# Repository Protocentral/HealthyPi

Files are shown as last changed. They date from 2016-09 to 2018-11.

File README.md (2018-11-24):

# This repository is OBSOLETE. Please visit https://github.com/Protocentral/protocentral-healthypi-v3 for the current version. 

# ProtoCentral HealthyPi HAT for Raspberry Pi

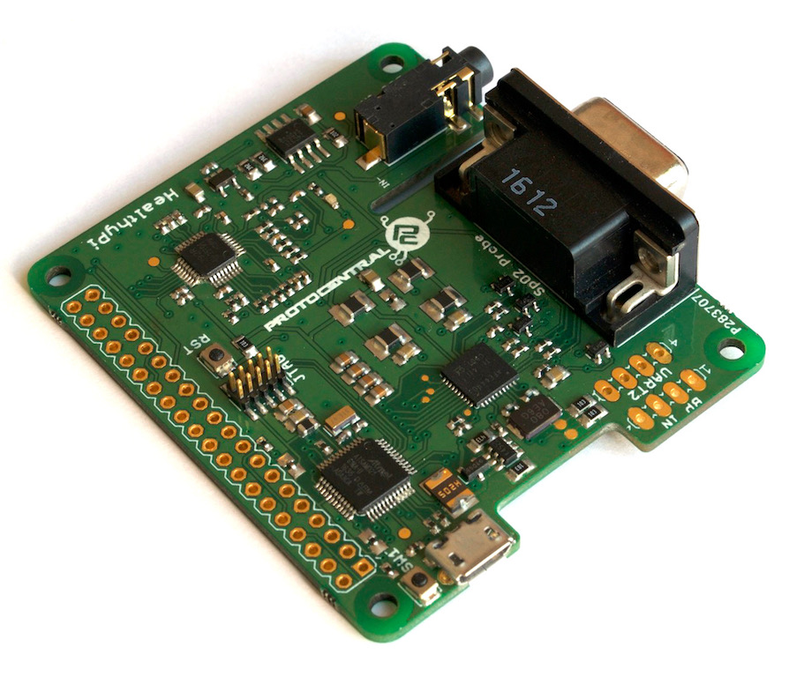
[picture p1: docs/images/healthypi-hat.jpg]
Healthy Pi Hat


This HAT for Raspberry Pi 3 / 2 includes vital patient monitoring including ECG, respiration, pulse oximetry and features options to add blood pressure and body temperature sensing.

This is a one-of-a-kind, all-in-one HAT for your Raspberry Pi 2 /3 computer. Just plug it into the Raspberry Pi, install the graphical visualisation software and start using. Unlike available shields and breakouts that we carry for Arduino, this board combines all the functions into a a single board.

Repository Contents
-------------------
* **/firmware** - Atmel studio  and aduino example sketches.
* **/Hardware** - All Eagle design files (.brd, .sch)
* **/extras** - includes the datasheet
* **/gui** - HealthyPi GUI for Raspberry Pi and PC
* **/docs** - Additional Documentation

Getting Started (On Raspberry Pi):
----------------------------------

Mount ProtoCentral's Healthy PI Hat carefully onto the Raspberry Pi Board's GPIO Pins. And connect this setup with the Raspberry Pi's Display or HDMI Monitor. The Hat communicate with Raspberry Pi using UART interface. Connect the ECG electrodes and SPO2 Probe to the ProtoCentral's Healthy PI Hat.

It's now easy to get started with our brand-new installation script. Just follow the following steps on your Raspberry Pi.

To start, open up the terminal window (Menu -> Accessories -> Terminal) on Raspbian running on your Raspberry Pi:

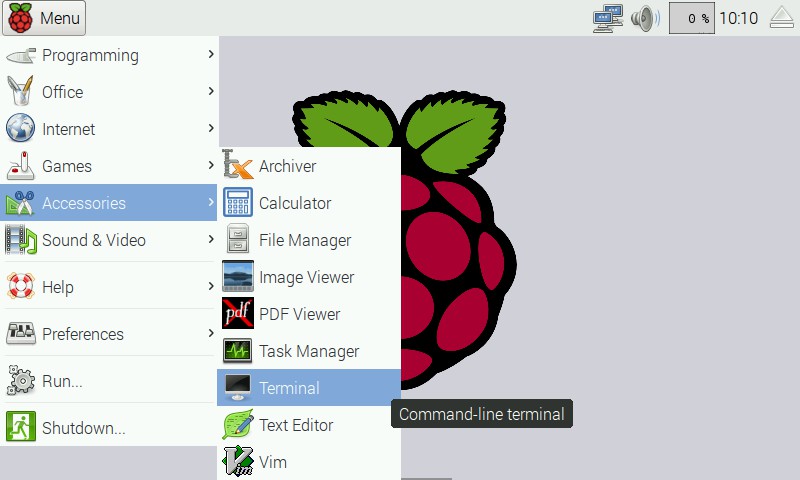
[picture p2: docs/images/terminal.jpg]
Open the terminal


In the terminal window, type the following lines. 

```bash
curl -sS http://pi.protocentral.com/pi.sh | sudo bash
```

It really is as simple as that !!

This code will install all the required overlays, configuration and application files to get the Healthy Pi up and running.

After the script reboots, you should be able to see the GUI display on the screen

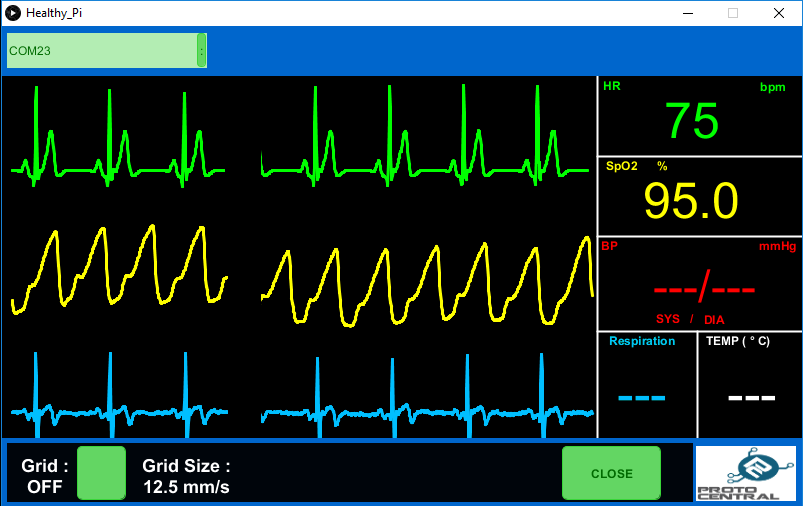
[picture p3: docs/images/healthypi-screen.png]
GUI in Processing


###This completes the install!

If the above script does not work for you and would like to do a manual installation or would like to customize the code, check out [Advanced HealthyPi] (/docs/advanced-healthypi.md).

Using the HealthyPi GUI on Windows, MacOS and Linux
---------------------------------------------------
The HealthyPi board now streams the same data on the on-board USB port. This allows you to get the same data that goes to the Raspberry Pi, now on your desktop PC as well. 

Java 8 is required on all platforms for running the processing-based GUI application. You can download Java for your platform from the following link.

[https://java.com/en/download/](https://java.com/en/download/)

#### Installing drivers (only for Windows)

HealthyPi uses the same drivers as an Arduino Zero. Once plugged in to the USB port, the device would be recognized as an "Unknown Device". You can locate the device is the Windows Device Manager and manually install the drivers provided in the "drivers" folder in the Windows Executable ZIP archive provided.

MacOS and Linux do not need any drivers to be installed.

### Processing GUI Installation

Download the zip file containing the executable files from the following links for 32-bit/64-bit Windows. If you do not know if you have a 64-bit or 32-bit computer, please download the 32-bit version.

* [Windows 32-bit Executable (ZIP)](https://github.com/Protocentral/HealthyPi/releases/download/v0.2/healthypi_gui_win32.zip)
* [Windows 64-bit Executable (ZIP)](https://github.com/Protocentral/HealthyPi/releases/download/v0.2/healthypi_gui_win64.zip)
* [MacOS Executable (ZIP)](https://github.com/Protocentral/HealthyPi/releases/download/v0.2/healthypi_gui_macos.zip)
* [Linux 32-bit Executable (ZIP)](https://github.com/Protocentral/HealthyPi/releases/download/v0.2/healthypi_gui_linux32.zip)
* [Linux 64-bit Executable (ZIP)](https://github.com/Protocentral/HealthyPi/releases/download/v0.2/healthypi_gui_linux64.zip)

Simply download the appropriate file for your operating system, unzip the contents and run the executable program contained in it. 

Programming the on-board SAMD21 microcontroller
--------------------------------------------------

HealthyPi now supports programming using Arduino ! 

If you wish to program your own code on the HealthyPi board, check out [Modifying and recompiling HealthyPi Firmware](/docs/recompiling-firmware.md).

Connecting the ECG Electrodes
------------------------------
 A 3-electrode cable along with a standard stereo jack is provided along with the shield to connect the electrodes to the  board. 
 The other side of the electrode connector would connect to snap-on electrodes attached to the body. For testing purposes,    you can use an ECG simulator to provide inputs to the board. 

 Warning:
 When connecting the electodes to the body, it is safer to disconnect the mains power source to the Arduino. For example, if  you are using the Arduino along with a laptop, disconnecting the battery charger from the laptop would be a safe option.
 
Placing the Electrodes on the body
---------------------------------
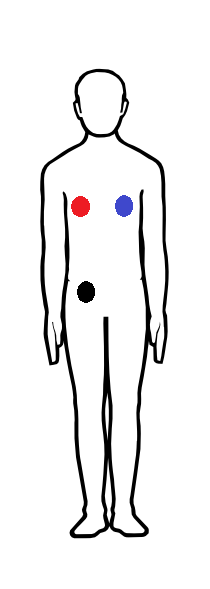
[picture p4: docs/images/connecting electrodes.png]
Wearing the Electrode


License Information
===================

This product is open source! Both, our hardware and software are open source and licensed under the following licenses:

Hardware
---------

**All hardware is released under [Creative Commons Share-alike 4.0 International](http://creativecommons.org/licenses/by-sa/4.0/).**



Software
--------

**All software is released under the MIT License(http://opensource.org/licenses/MIT).**

Please check [*LICENSE.md*](LICENSE.md) for detailed license descriptions.

THE SOFTWARE IS PROVIDED "AS IS", WITHOUT WARRANTY OF ANY KIND, EXPRESS OR
IMPLIED, INCLUDING BUT NOT LIMITED TO THE WARRANTIES OF MERCHANTABILITY,
FITNESS FOR A PARTICULAR PURPOSE AND NONINFRINGEMENT. IN NO EVENT SHALL THE
AUTHORS OR COPYRIGHT HOLDERS BE LIABLE FOR ANY CLAIM, DAMAGES OR OTHER
LIABILITY, WHETHER IN AN ACTION OF CONTRACT, TORT OR OTHERWISE, ARISING FROM,
OUT OF OR IN CONNECTION WITH THE SOFTWARE OR THE USE OR OTHER DEALINGS IN THE
SOFTWARE.

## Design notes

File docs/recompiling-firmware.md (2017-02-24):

Recompiling Firmware:
---------------------

All boards shipped on or after February 20, 2017 come **pre-installed** with the Arduino Zero/M0 bootloader and the Arduino-based code. This means that you no longer need a JTAG programmer or Atmel Studio to customize the code on the SAMD21 microcontroller on the board. 

In addition, the new Arduino-based firmware now **streams over USB** the same data sent to the Raspberry Pi's UART pins. This now means that the HealthyPi works not just with a Raspberry Pi, but any Windows/MAC/Linux machine that supports Java and Processing.
 
However, if you would like to edit the firmware, here's the steps to do that in Atmel Studio 7:

* **Atmel Studio 7** :
Please note that Atmel Studio 7 is available only for Windows and does not support Mac and Linux . This is the IDE software that can do step & memory debugging and its only for Windows. Also you have to make an account on Atmel's site. The IDE can be downloaded from [Atmel Studio's Official Website](http://www.atmel.com/tools/atmelstudio.aspx)

**Load the Healthy Pi Source Code**

* **Step 1 :** Start by launching Atmel Studio 7.

* **Step 2 :** Open the Project file in the firmware folder of this git respitory

* **Step 3 :** You'll see the following, where the sketch is in a window, you can edit the code here if you like.

**Debugger**

You need a debugger to load the code into the SAMD21G18A. Atmel-ICE will help get from here http://www.atmel.com/tools/atatmel-ice.aspx

**Step 1 : Set Up and Check Interface**
* Attach the chip & debugger

**Step 2 : Identify Interface**
* OK now you have your debugger plugged in, its good to check that it works, select Device Programming.
* Choose "Device Programmer" from "Tools" Menu
* Programming window will be open.
* Select the programmer from the drop down box. Select interface as “SWD”. Click on “Apply”.
* Now read the Power and Device ID. If you are able to read the Device ID then the interface is fine.

**Step 3 : Build & Start Debugging**
* Ok close out the modal programming window and build the program. If there are no error, then your build will be successful.

**Step 4 : Run & Upload**
* You will see a window appearing to select a debugging tool. Select the tool and interface.
* Once done, go back and Re-run Program without debugging.

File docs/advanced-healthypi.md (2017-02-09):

Advanced HealthyPi
==================
This section is for those who want to do a manual installation of HealthyPi, those who want to modify with the code and generally play with the hardware.

For the simple way to setup HealthyPi on Raspberry Pi, check out the [getting started guide](https://github.com/protocentral/healthypi).

You can buy [HealthyPi at ProtoCentral](https://www.protocentral.com/healthypi)

Setting up Raspberry Pi for UART Communication
----------------------------------------------
The following are the steps involved to get Raspberry Pi ready for a patient monitor.

###Step 1 : Install and Update the OS

* Install the Raspbian OS in Raspberry Pi. The image file can be downloaded from the [Raspberry Pi's official website](https://www.raspberrypi.org/downloads/).

* Once the installation finishes, update the system with the following command in the Terminal:
		
		sudo apt-get update
		sudo apt-get upgrade

###Step 2 : Enable the UART0 device tree overlay

As the ProtoCentral's Healthy Pi Hat communicates with the Raspberry Pi board via GPIO 14/15 which on the Model B, B+ and Pi2 is mapped to UART0. However on the Pi3 these pins are mapped to UART1 since UART0 is now used for the bluetooth module. As UART1 is not stable because it is dependent to clock speed which can change with the CPU load, we have to disable the Bluetooth module and map UART1 back to UART0 (tty/AMA0).

* Run the following command

		sudo nano /boot/config.txt

* Add this line to the end of the file

		dtoverlay=pi3-miniuart-bt

###Step 3 : Disable Serial command line console

* To disable the Serial Console edit the file using

		sudo nano /boot/cmdline.txt 

* Remove the word phase "console=serial0,115200" or "console=ttyAMA0,115200".

* Save the file and close

###Step 4 : Reboot your Raspberry Pi

* Now your Pi is ready to integrate with ProtoCentral's Healthy Pi Hat.

HealthyPi GUI based on Processing
---------------------------------

[Processing](https://processing.org/) has been used to develop the visualization software for the HealthyPi. 

Processing is an open source framework based on Java. The following are the steps to get the visualization software ready for patient monitor:

###Step 1 : Download Processing IDE for your HOST COMPUTER operating system

a. Latest Version of the Processing IDE can be downloaded from the following link:

[Download Processing](https://processing.org/download/?processing)

b. Unzip and install the file once downloaded.

###Step 2 : Download the Processing code for the HealthyPi GUI

a. Download the necessary files & directories or clone to your desktop from GitHub.

b. Unzipping the archive should make a folder by name HealthyPi that contains the visualisation code.

c. Locate the Processing sketchbook directory on your computer. This should have been created automatically when you installed processing. Depending on your operating system, the path will be as follows:

* On Windows : C:/My Documents/Processing
* On MAC : /Users/your_user_name/Documents/Processing
* On Linux : /Home/your_user_name/sketchbook/

**Note:** This directory appears as "Processing" on Windows/Mac, and goes by the name "Sketchbook" on Linux. Create a subdirectory by name "libraries if one doesn't exist already.

d. From the above mentioned "HealthyPi" directory Copy/Move the contents of the HealthyPi/Processing/HealthyPi folder to the Processing sketchbook directory which is also mentioned above (Locate the Processing sketchbook)

e. Finally, copy the "controlP5 & G4P" folders from HealthyPi/Processing/libraries/ and paste them into the libraries directory of your Processing sketchbook.

###Step 3 : Upload the Processing code Raspberry Pi

* In Processing IDE, Select "Tools" from the menu and choose, "Add tools".

* Select "Upload To Pi" tool and click Install button which is present in the button right corner as shown in the below image.

![Upload To Pi in Processing]
(https://github.com/Protocentral/HealthyPi/blob/master/extras/Images/Upload_To_Pi.png)

* Now, connect your raspberry pi to the internet with the same network as your laptop is connected.

* Select "Tools" menu and choose "Upload to Pi" option from the list.

* If any error occured in uploading the code, check for the internet connection and repeat the process.

Firmware:
---------

The board is pre-loaded with the firmware which works stand alone with the Rpi without any firmware development or loading required. 

However, if you want to edit the firmware, you can follow the steps in this [document] (/docs/recompiling-firmware.md)

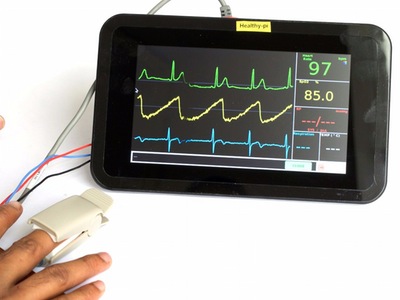
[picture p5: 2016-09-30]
docs/images/healthypi-run.jpg

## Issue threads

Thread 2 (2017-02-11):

Documentation for the serial protocol

abhas, 2017-02-11:
I see that the HealthyPi communicates with the Raspberry Pi using a serial protocol. But the only way to understand how this happens would be to study the Processing source code. If you could share any documentation of the serial protocol, that would be very helpful in using the board to gather and store metrics using time-series databases, for example. Or just write some simple C or Python code to understand how the board works.

protocentralashwin, 2017-02-12:
We will document the protocol as well, but for now you can check the trasnmit protocol format in the following code:

https://github.com/Protocentral/HealthyPi/blob/master/firmware/src/main.c

Closed 2017-02-12.

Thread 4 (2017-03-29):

Wrong Baudrate in INO?

SvenHi, 2017-03-29:
In the arduino sktech, there is the baud rate config for 115200
in all GUI and Atmel Studio project 57600.

=> Is the Arduino sketch really up to date?
Even if I change the baud rate, I get no matching values in the GUI

VenkateshBhat, 2017-03-30:
Hello SvenHi,
The SerialUSB on Arduino Zero is a  is an emulated serial port (USB-CDC). The SerialUSB class is a special Serial instance which use the hardware USB the speed will always be 115200.

SvenHi, 2017-03-30:
 

Thank you for response!

Does this mean, I have to change the Baudrate in the Processing GUI (for USB)?

Original code healthypi_desktop.pde:     port = new Serial(this, selectedPort, 57600);

Or does this setting not matter?

In case this setting does not cause conflict with the 115200 baudrate of CDC, I have to search for other issues on my setup.

I have the problem, that the device does work in general with Atmel Studio firmware on Raspberry.

If I replace the flash with Arduino Zero bootloader, download INO via Arduino, and use the PC GUI (Win10,64Bit)

then I have in general communication between device and GUI, but no valid data in visualization...

Best regard

Gesendet: Donnerstag, 30. März 2017 um 07:33 Uhr
Von: VenkateshBhat <notifications@github.com>
An: Protocentral/HealthyPi <HealthyPi@noreply.github.com>
Cc: SvenHi <s.hirsch@gmx.net>, Author <author@noreply.github.com>
Betreff: Re: [Protocentral/HealthyPi] Wrong Baudrate in INO? (#4)

Hello SvenHi,
The SerialUSB on Arduino Zero is a is an emulated serial port (USB-CDC). The SerialUSB class is a special Serial instance which use the hardware USB the speed will always be 115200.

—
You are receiving this because you authored the thread.
Reply to this email directly, view it on GitHub, or mute the thread.

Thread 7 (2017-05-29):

ECG Not working

saisrinivas25, 2017-05-29:
I tried to connect the electrodes as mentioned in the diagram.
But it doesn't work properly and I am getting an unusual heart rate on the monitor.
It keeps on fluctuating. Kindly let me know the proper connections in detail.

VenkateshBhat, 2017-05-29:
Could you please attach the screenshot of signals obtained?

saisrinivas25, 2017-05-29:
Here are the screenshots.
Somehow, the record was not working on my PC.
So I have taken these snapshots.
Issue is only with ECG, SpO2 is working fine I guess.
And I have red, blue and black coloured electrodes. please let me know the electrodes' spec properly.
I mean, which is RA, LA & LL?
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

VenkateshBhat, 2017-05-29:
Thanks for sharing, where did you place the electrodes? was it on the chest?. Baseline is wandering too much.
RA : Red
LA: Green
LL : Black

saisrinivas25, 2017-05-29:
Thanks for the info. So, I had placed the electrodes in proper positions.
I had tried placing the electrodes both on the chest and on limbs as well.
But I got the same kind of fluctuating reading.

saisrinivas25, 2017-05-29:
What is the baseline you are referring to?
I understand that green is heart rate, blue is respiration and yellow is SpO2.
But, is there anything else I need to understand from the GUI?
And why there are readings on the GUI even when there are no devices(ECG or SpO2) connected to the HealthyPI?
Please help

VenkateshBhat, 2017-05-29:
I am referring to the ECG signal moving up and down  rather than straight.  Are you using the latest Ui?

saisrinivas25, 2017-05-29:
Yes. I am using V0.3

saisrinivas25, 2017-05-30:
Can you please tell me what the conclusion is?
Is the HealthyPi hat faulty? It is showing readings when there is no device connected also.
Or how can I get proper readings of my vitals?
Please advise

famesjranko, 2022-04-07:
I just got the latest v4 and also has readings showing when no device connected.   I think there are serious design/implementation issues with this device...

MohammedHM, 2022-04-08:
Hi Andrew,

Can you please share the screenshots of the output, and the image of your HealthyPi setup.

famesjranko, 2022-04-20:
Hey MohammedHM,

Thanks for responding.   I've been trying to figure out the packet data structure and encoding come through the raspberry pi port serial /dev/ttyAMA0 without any luck.   Could you please point me towards the documentation for this?

Looking at the gui.java file located in the source directory, I was able to see that you are writing to CSV file and thought about editing that section to parse the data where I want to send it, but I found that I can't compile that file and the actual code being used is in .jar files and thus inaccessible to me.   Would it be possible to have access to these files for easier modding?

The reason I was interested in your project and bought the device was the open-source nature of it, but I've found the software to be opaque rather than transparent...

I will provide screenshots shortly, but simply put I get a heart rate even when there are no sensors connected, and the spO2 sensor only gives values when the ecg sensors are connected - not sure if that last one is a design or a bug...

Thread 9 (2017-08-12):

No Raspberry Pi serial data from Arduino firmware

GothAck, 2017-08-12:
The firmware outputs via SerialUSB but I cannot see any code to output to the pi via GPIO.

abhas, 2017-08-12:
I think the HealthyPi board talks to the RPi via the serial port on the GPIO pins. So it doesn't use the GPIO *per se* -- only the serial port on the GPIO.

GothAck, 2017-08-12:
It is meant to, yes, but after flashing the latest arduino code I see no data being sent to the RPi. I've tried searching through the code but can only see transmission of the packets via SerialUSB, which IIRC is just the USB CDC serial port. The USB serial device is transmitting data just fine, just not via the RPi GPIO header.

protocentralashwin, 2017-08-12:
thanks guys @GothAck and @abhas . We have moved the latest version of this repo for HealthyPi v3 to https://github.com/Protocentral/protocentral-healthypi-v3/

The code is actually sending to both _SerialUSB_ as well as _Serial_

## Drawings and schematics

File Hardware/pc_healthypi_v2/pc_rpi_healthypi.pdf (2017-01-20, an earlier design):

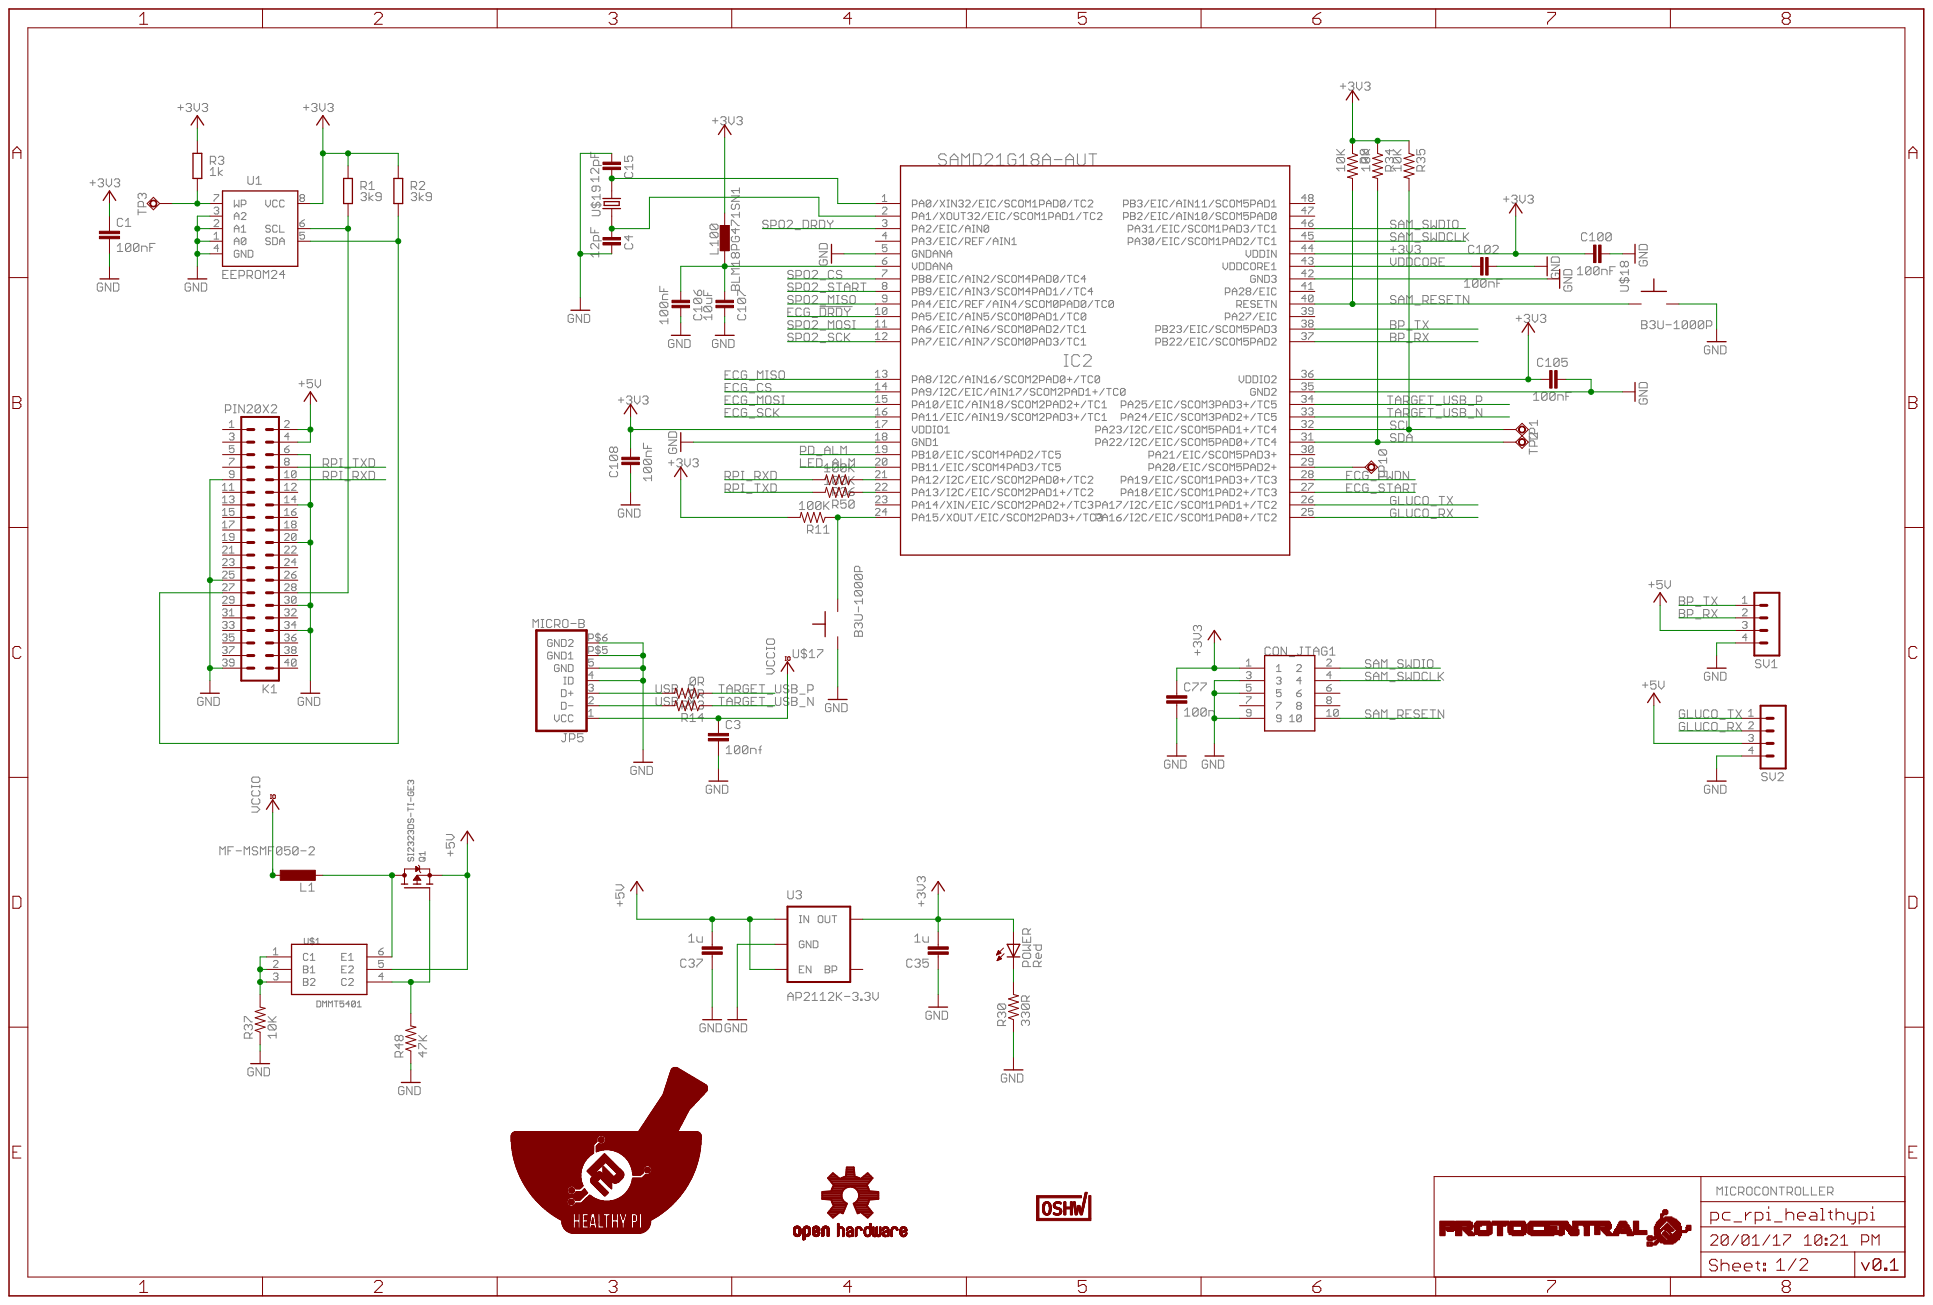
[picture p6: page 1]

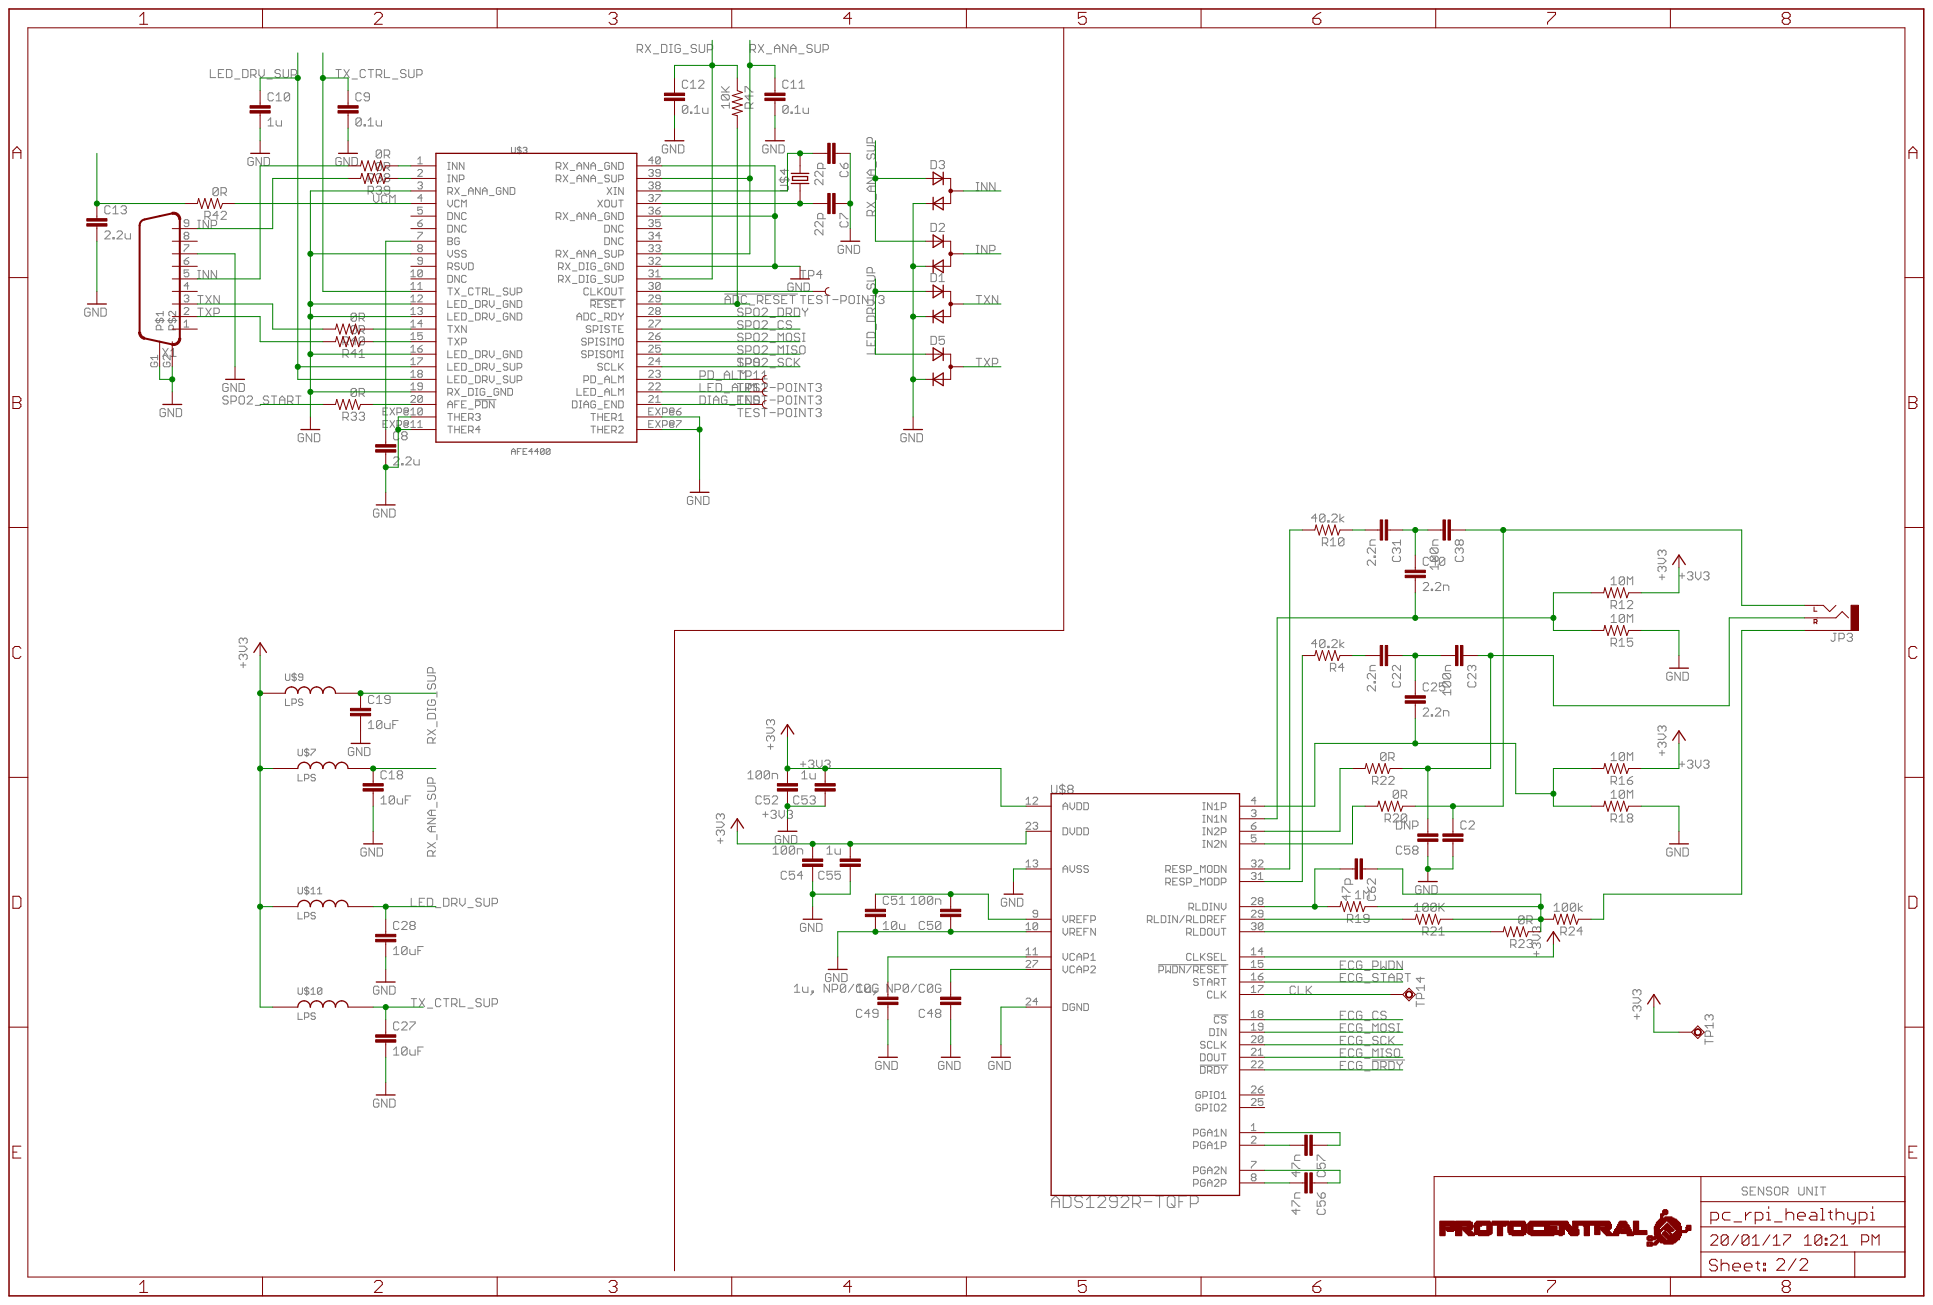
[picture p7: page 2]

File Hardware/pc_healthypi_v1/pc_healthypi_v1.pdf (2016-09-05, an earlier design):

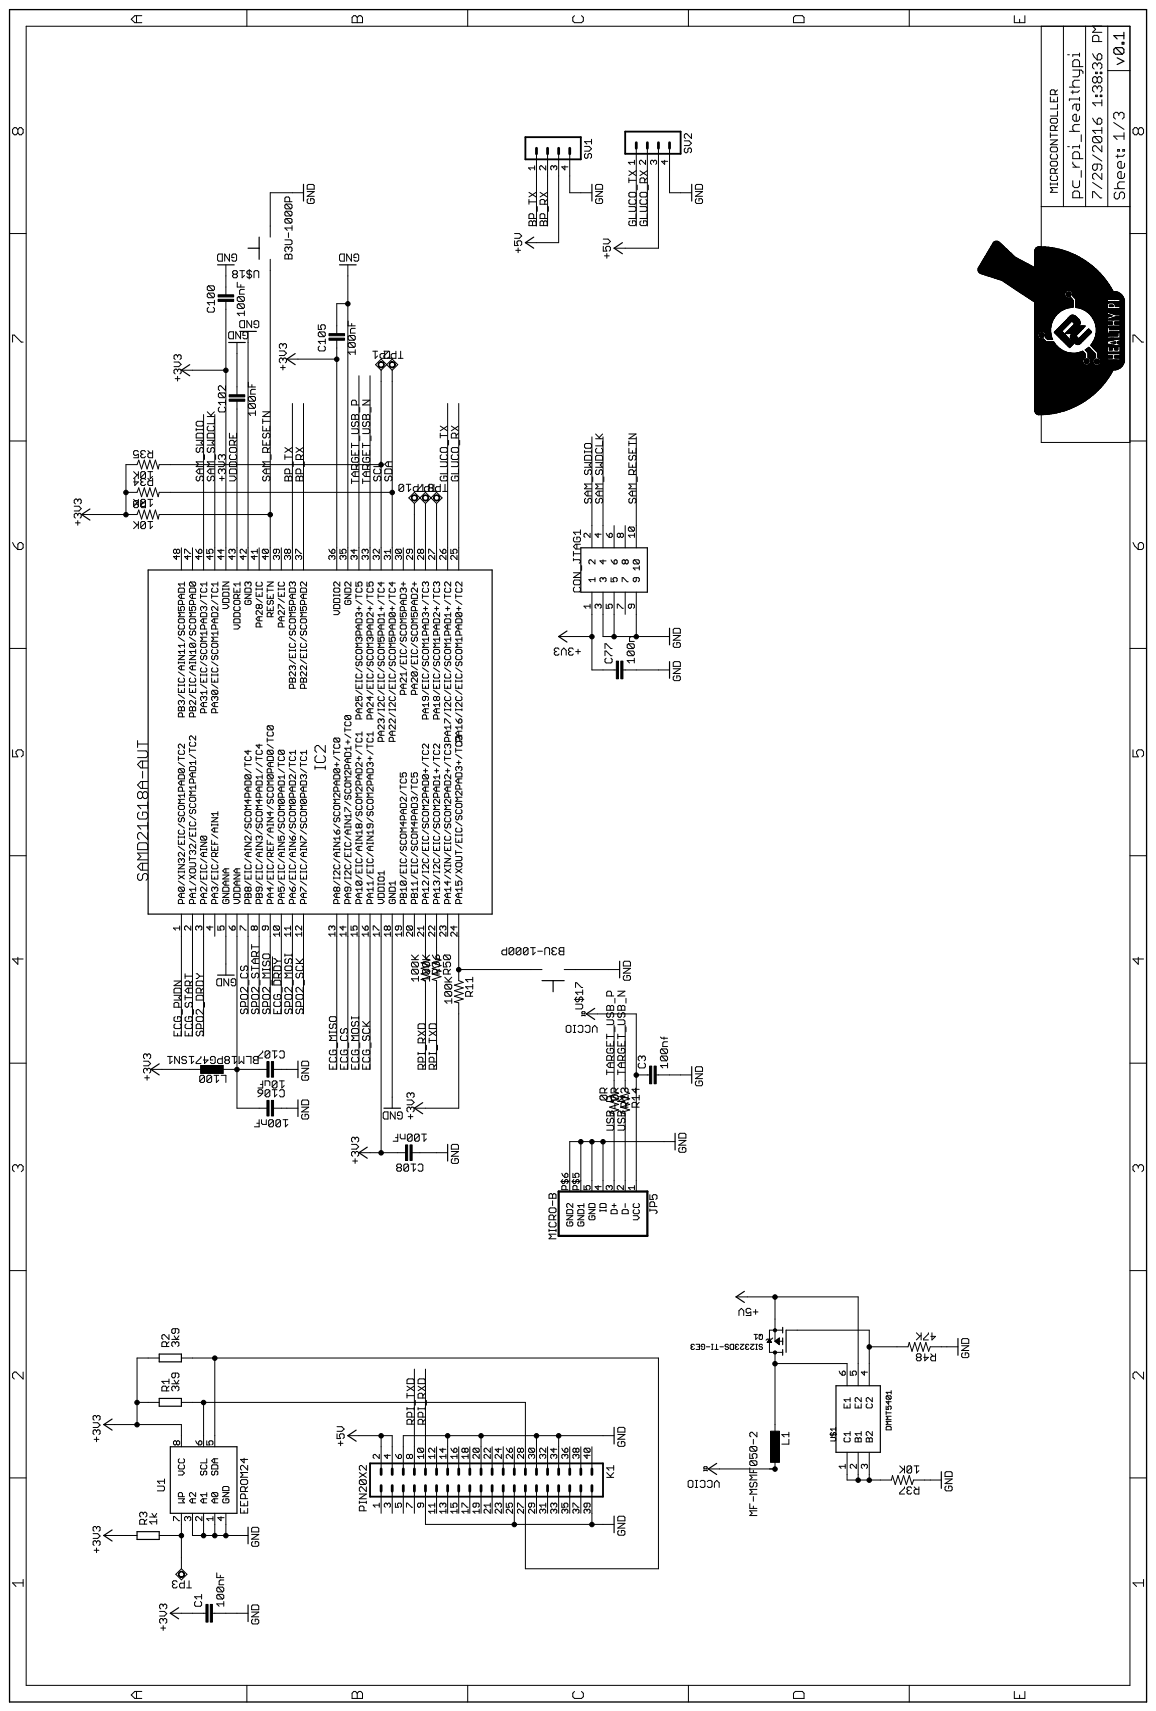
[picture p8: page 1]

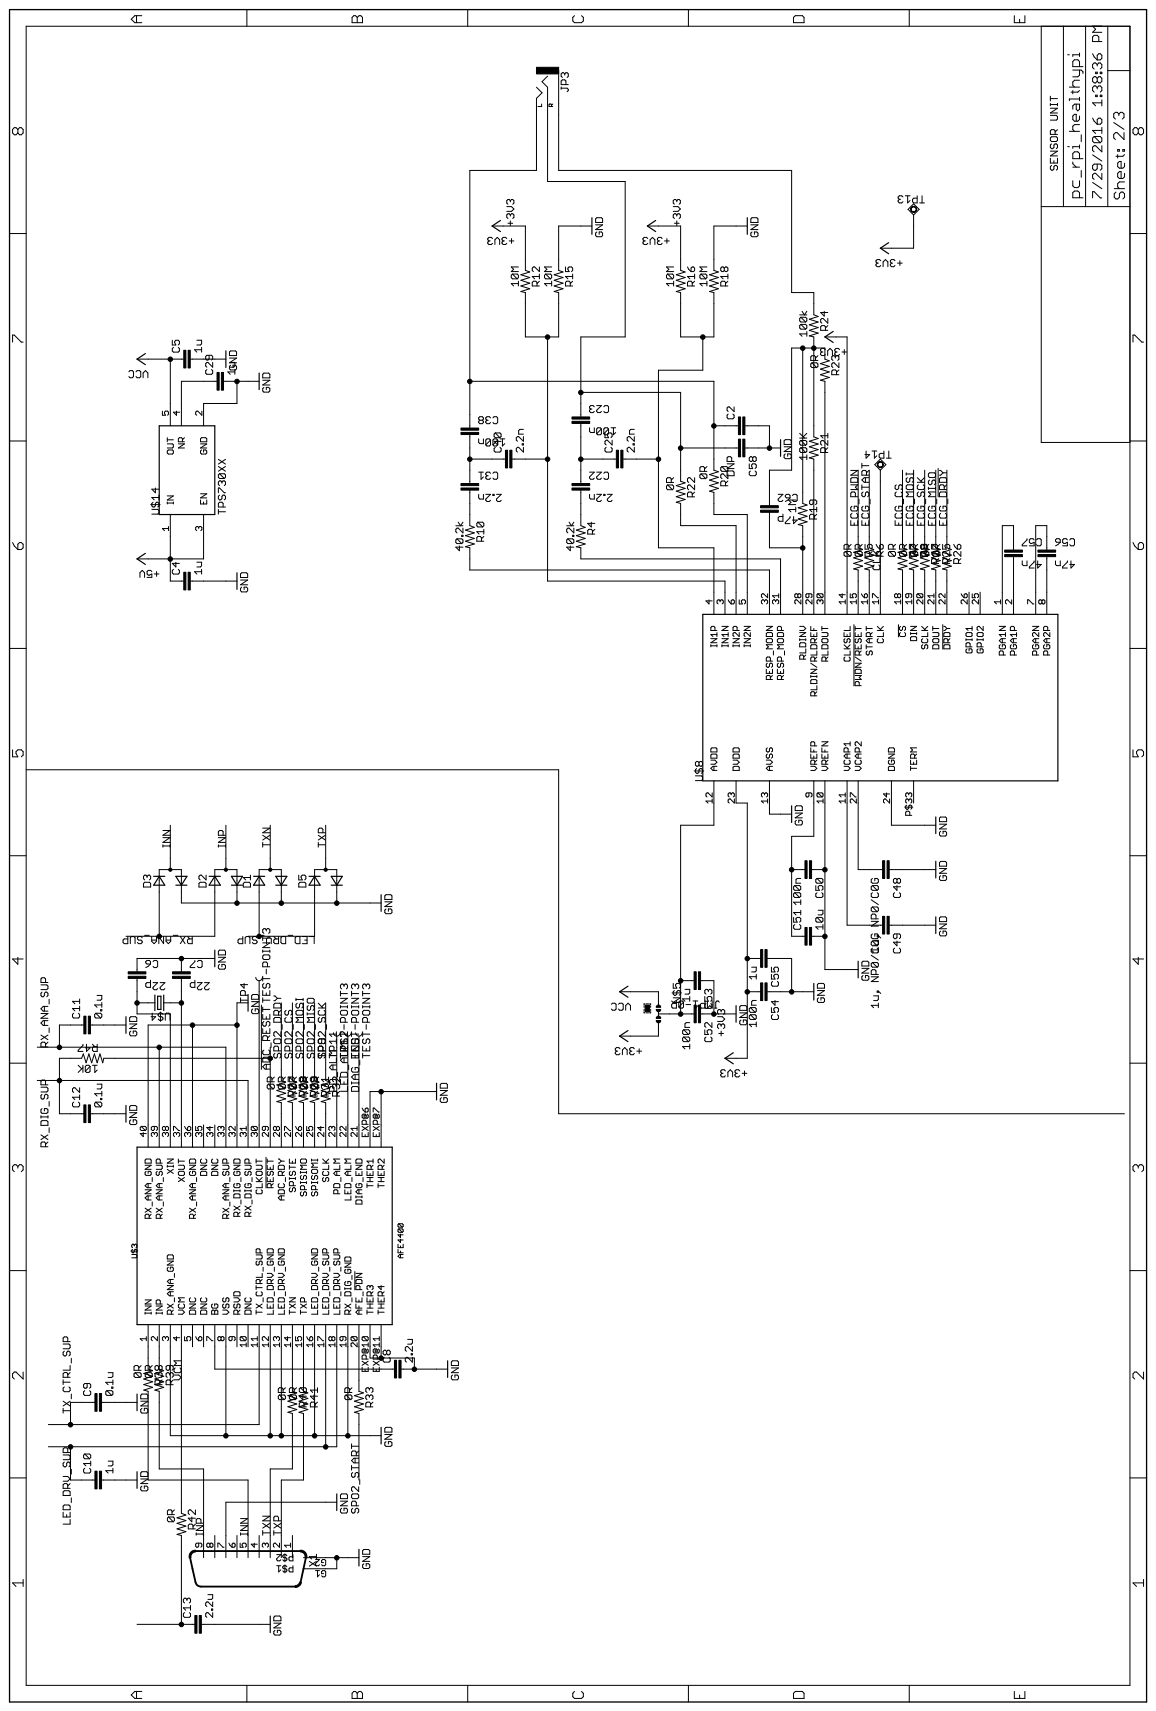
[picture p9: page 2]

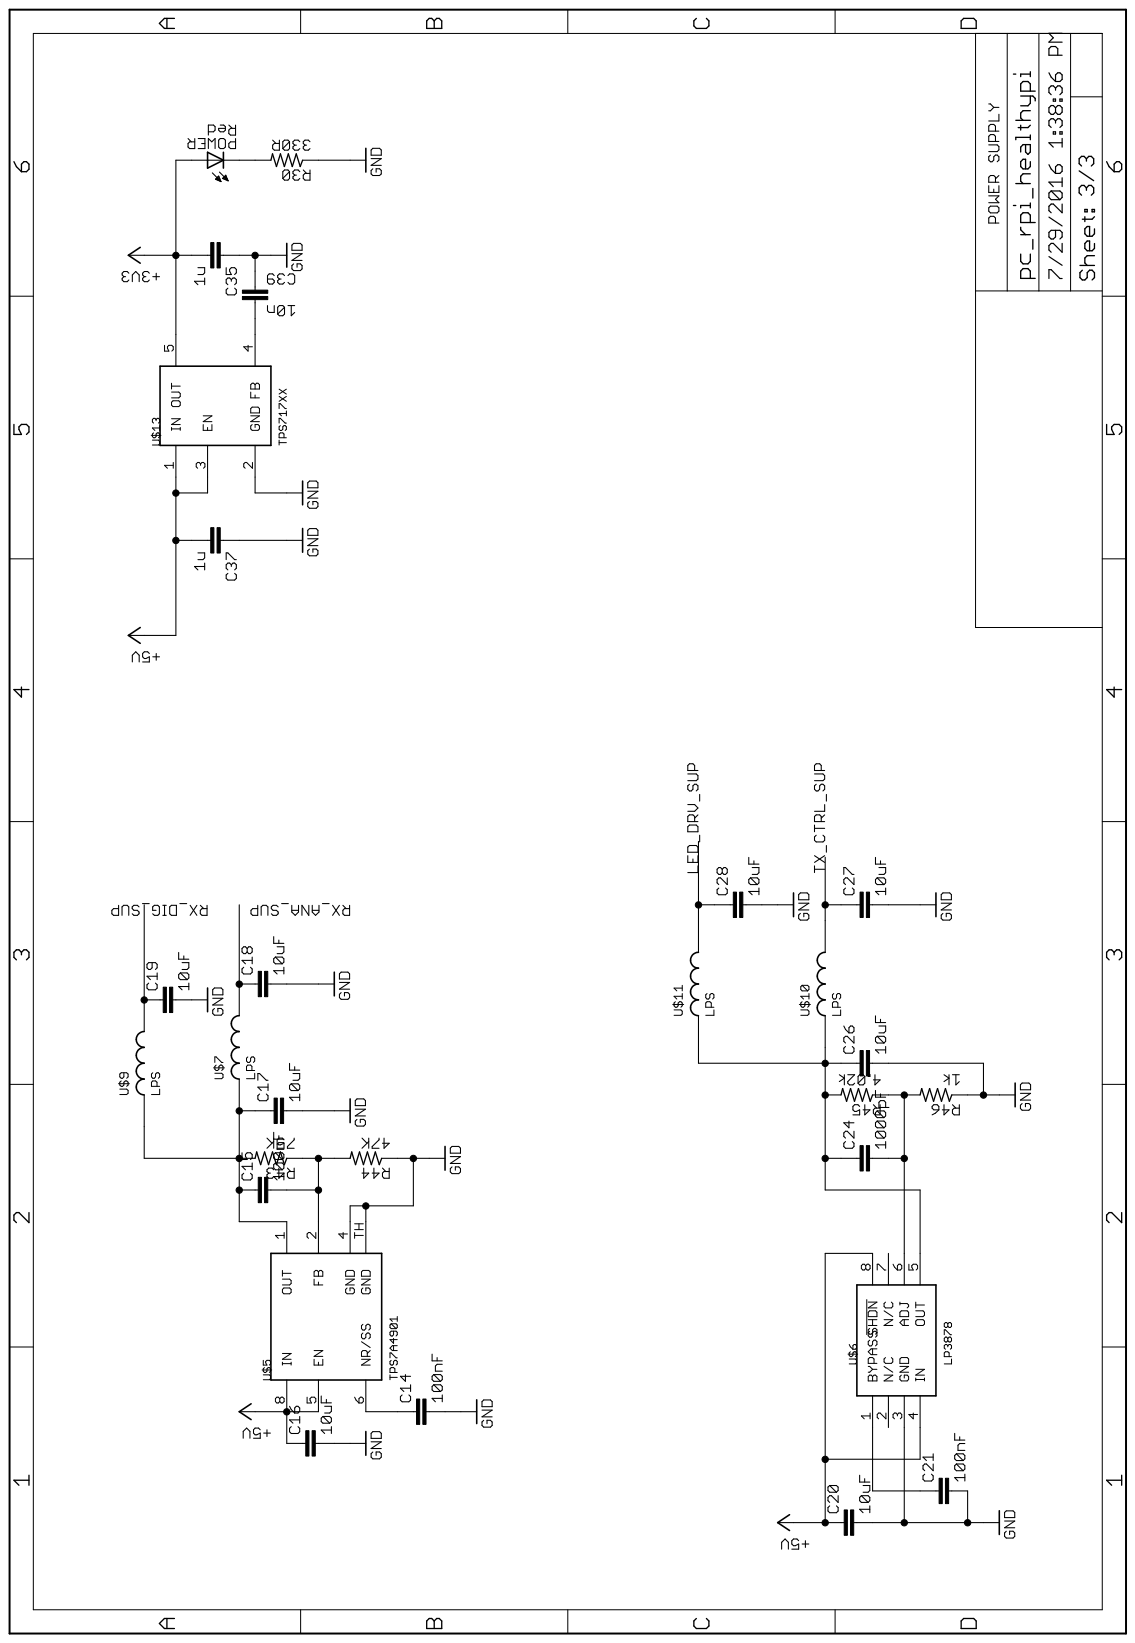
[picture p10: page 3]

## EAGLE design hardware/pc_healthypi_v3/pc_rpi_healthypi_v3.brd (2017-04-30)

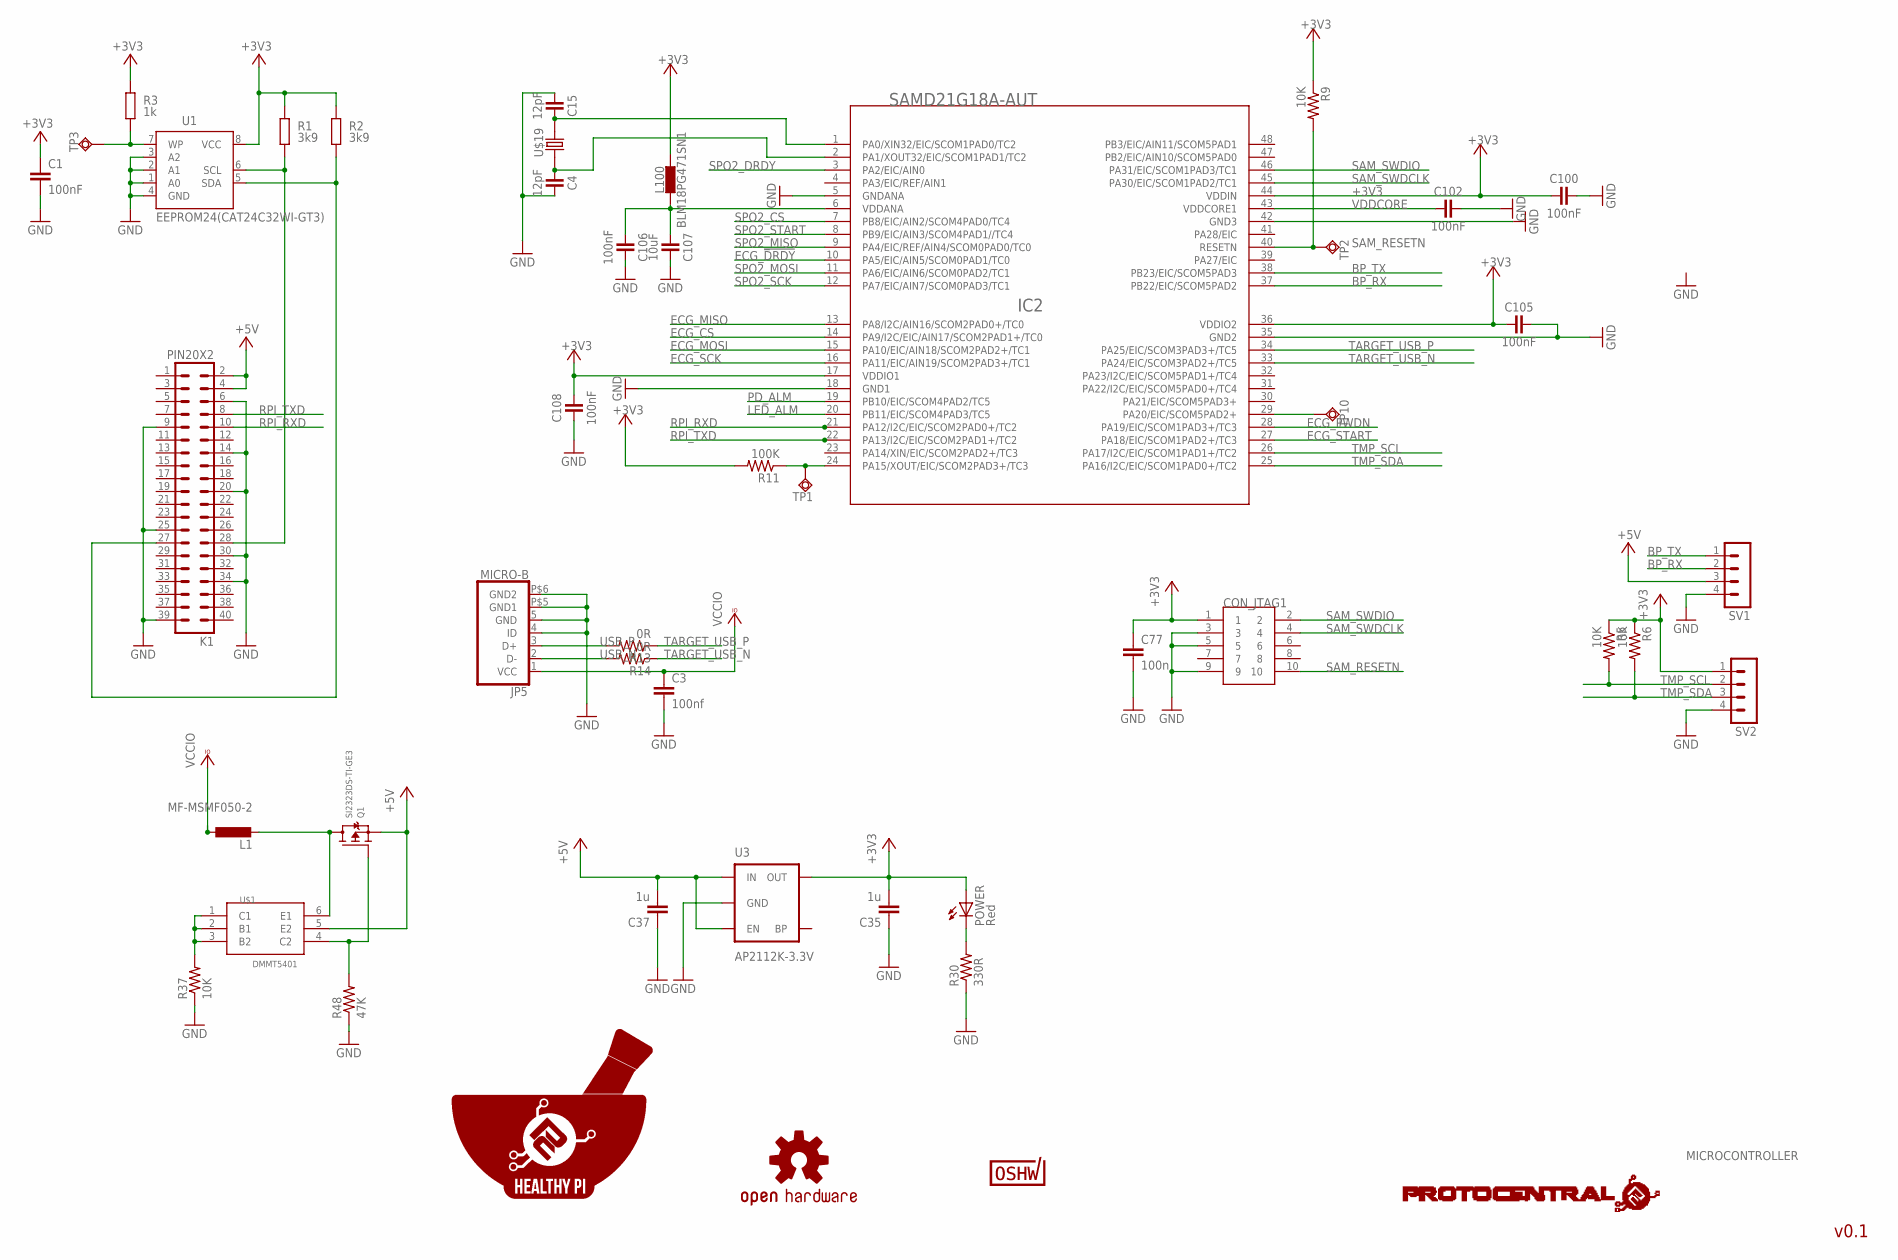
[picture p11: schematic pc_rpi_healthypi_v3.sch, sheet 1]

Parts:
C1: 100nF; C0805K
C3: 100nf; C0402
C4, C15: 12pF; C0402
C35, C37: 1u; C0402
C77: 100n; C0805
C100, C102, C105, C106, C108: 100nF; C0805
C107: 10uF; C0805
CON_JTAG1: HDR-SMT-50MIL/5X2(20021121-00010C4LF); HDR-SMT-50MIL/5X2
IC2: SAMD21G18A-AUT; TQFP48
JP5: MICRO-B
K1: PIN20X2; PIN_20X2
L1: MF-MSMF050-2; L1812
L100: BLM18PG471SN1; C0603
POWER: Red; CHIPLED_0603
Q1: SI2323DS-TI-GE3; SOT23-R
R1, R2: 3k9; M0805; TOLERANCE 5%
R3: 1k; M0805; TOLERANCE 5%
R5, R6: 10K; R0402
R9, R37: 10K; R0805
R11: 100K; R0805
R13, R14: 0R; R0402
R30: 330R; R0402
R48: 47K; R0805
SV1, SV2: MA04-1
TP1, TP2, TP3, TP10: TPSQB1,27; B1,27
U1: EEPROM24(CAT24C32WI-GT3); SOIC8
U3: AP2112K-3.3V; SOT23-5
U$1: DMMT5401; SOT26
U$5: OSHW-LOGOM; OSHW-LOGO-M
U$6: PROTY_LOGO_WITH_TEXT; PROTY_WITH_TEXT
U$13: CERT-SMALL; CERT-SMALL-SILK
U$15: HEALTHYPI
U$19: 520-327-12.5-34B(32.768KHZ); ECX-31B

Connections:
+3V3: C1.1, C35.2, C77.1, C100.1, C105.1, C108.2, CON_JTAG1.1, IC2.17 (VDDIO1), IC2.36 (VDDIO2), IC2.44 (VDDIN), L100.2, POWER.A, R1.2, R2.2, R3.2, R5.1, R6.1, R9.1, R11.2, SV2.1, U1.8 (VCC), U3.5 (OUT); also elsewhere on the board
+5V: C37.2, K1.2, K1.4, Q1.2 (S), SV1.3, U3.1 (IN), U3.3 (EN), U$1.5 (E2)
BP_RX: IC2.37 (PB22/EIC/SCOM5PAD2), SV1.2
BP_TX: IC2.38 (PB23/EIC/SCOM5PAD3), SV1.1
ECG_!DRDY: IC2.10 (PA5/EIC/AIN5/SCOM0PAD1/TC0); also elsewhere on the board
ECG_CS: IC2.14 (PA9/I2C/EIC/AIN17/SCOM2PAD1+/TC0); also elsewhere on the board
ECG_MISO: IC2.13 (PA8/I2C/AIN16/SCOM2PAD0+/TC0); also elsewhere on the board
ECG_MOSI: IC2.15 (PA10/EIC/AIN18/SCOM2PAD2+/TC1); also elsewhere on the board
ECG_PWDN: IC2.28 (PA19/EIC/SCOM1PAD3+/TC3); also elsewhere on the board
ECG_SCK: IC2.16 (PA11/EIC/AIN19/SCOM2PAD3+/TC1); also elsewhere on the board
ECG_START: IC2.27 (PA18/EIC/SCOM1PAD2+/TC3); also elsewhere on the board
GND: C1.2, C3.2, C4.2, C15.1, C35.1, C37.1, C77.2, C100.2, C102.2, C105.2, C106.2, C107.2, C108.1, CON_JTAG1.3, CON_JTAG1.5, CON_JTAG1.9, IC2.5 (GNDANA), IC2.18 (GND1), IC2.35 (GND2), IC2.42 (GND3), JP5.4 (ID), JP5.5 (GND), JP5.P$5 (GND1), JP5.P$6 (GND2), K1.6, K1.9, K1.14, K1.20, K1.25, K1.30, K1.34, K1.39, R30.1, R37.1, R48.1, SV1.4, SV2.4, U1.1 (A0), U1.2 (A1), U1.3 (A2), U1.4 (GND), U3.2 (GND); also elsewhere on the board
LED_ALM: IC2.20 (PB11/EIC/SCOM4PAD3/TC5); also elsewhere on the board
unnamed: K1.28, R1.1, U1.6 (SCL)
unnamed: K1.27, R2.1, U1.5 (SDA)
unnamed: R3.1, TP3.TP, U1.7 (WP)
unnamed: C15.2, IC2.1 (PA0/XIN32/EIC/SCOM1PAD0/TC2), U$19.P$2 (2)
unnamed: C106.1, C107.1, IC2.6 (VDDANA), L100.1
unnamed: POWER.C, R30.2
unnamed: C4.1, IC2.2 (PA1/XOUT32/EIC/SCOM1PAD1/TC2), U$19.P$1 (1)
unnamed: IC2.24 (PA15/XOUT/EIC/SCOM2PAD3+/TC3), R11.1, TP1.TP
unnamed: IC2.29 (PA20/EIC/SCOM5PAD2+), TP10.TP
unnamed: R37.2, U$1.1 (C1), U$1.2 (B1), U$1.3 (B2)
unnamed: Q1.1 (G), R48.2, U$1.4 (C2)
unnamed: L1.2, Q1.3 (D), U$1.6 (E1)
PD_ALM: IC2.19 (PB10/EIC/SCOM4PAD2/TC5); also elsewhere on the board
RPI_RXD: IC2.21 (PA12/I2C/EIC/SCOM2PAD0+/TC2), K1.10
RPI_TXD: IC2.22 (PA13/I2C/EIC/SCOM2PAD1+/TC2), K1.8
SAM_RESETN: CON_JTAG1.10, IC2.40 (RESETN), R9.2, TP2.TP
SAM_SWDCLK: CON_JTAG1.4, IC2.45 (PA30/EIC/SCOM1PAD2/TC1)
SAM_SWDIO: CON_JTAG1.2, IC2.46 (PA31/EIC/SCOM1PAD3/TC1)
SPO2_CS: IC2.7 (PB8/EIC/AIN2/SCOM4PAD0/TC4); also elsewhere on the board
SPO2_DRDY: IC2.3 (PA2/EIC/AIN0); also elsewhere on the board
SPO2_MISO: IC2.9 (PA4/EIC/REF/AIN4/SCOM0PAD0/TC0); also elsewhere on the board
SPO2_MOSI: IC2.11 (PA6/EIC/AIN6/SCOM0PAD2/TC1); also elsewhere on the board
SPO2_SCK: IC2.12 (PA7/EIC/AIN7/SCOM0PAD3/TC1); also elsewhere on the board
SPO2_START: IC2.8 (PB9/EIC/AIN3/SCOM4PAD1//TC4); also elsewhere on the board
TARGET_USB_N: IC2.33 (PA24/EIC/SCOM3PAD2+/TC5), R14.1
TARGET_USB_P: IC2.34 (PA25/EIC/SCOM3PAD3+/TC5), R13.1
TMP_SCL: IC2.26 (PA17/I2C/EIC/SCOM1PAD1+/TC2), R5.2, SV2.2
TMP_SDA: IC2.25 (PA16/I2C/EIC/SCOM1PAD0+/TC2), R6.2, SV2.3
USB_N: JP5.2 (D-), R14.2
USB_P: JP5.3 (D+), R13.2
VCCIO: C3.1, JP5.1 (VCC), L1.1
VDDCORE: C102.1, IC2.43 (VDDCORE1)

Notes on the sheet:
v0.1
MICROCONTROLLER

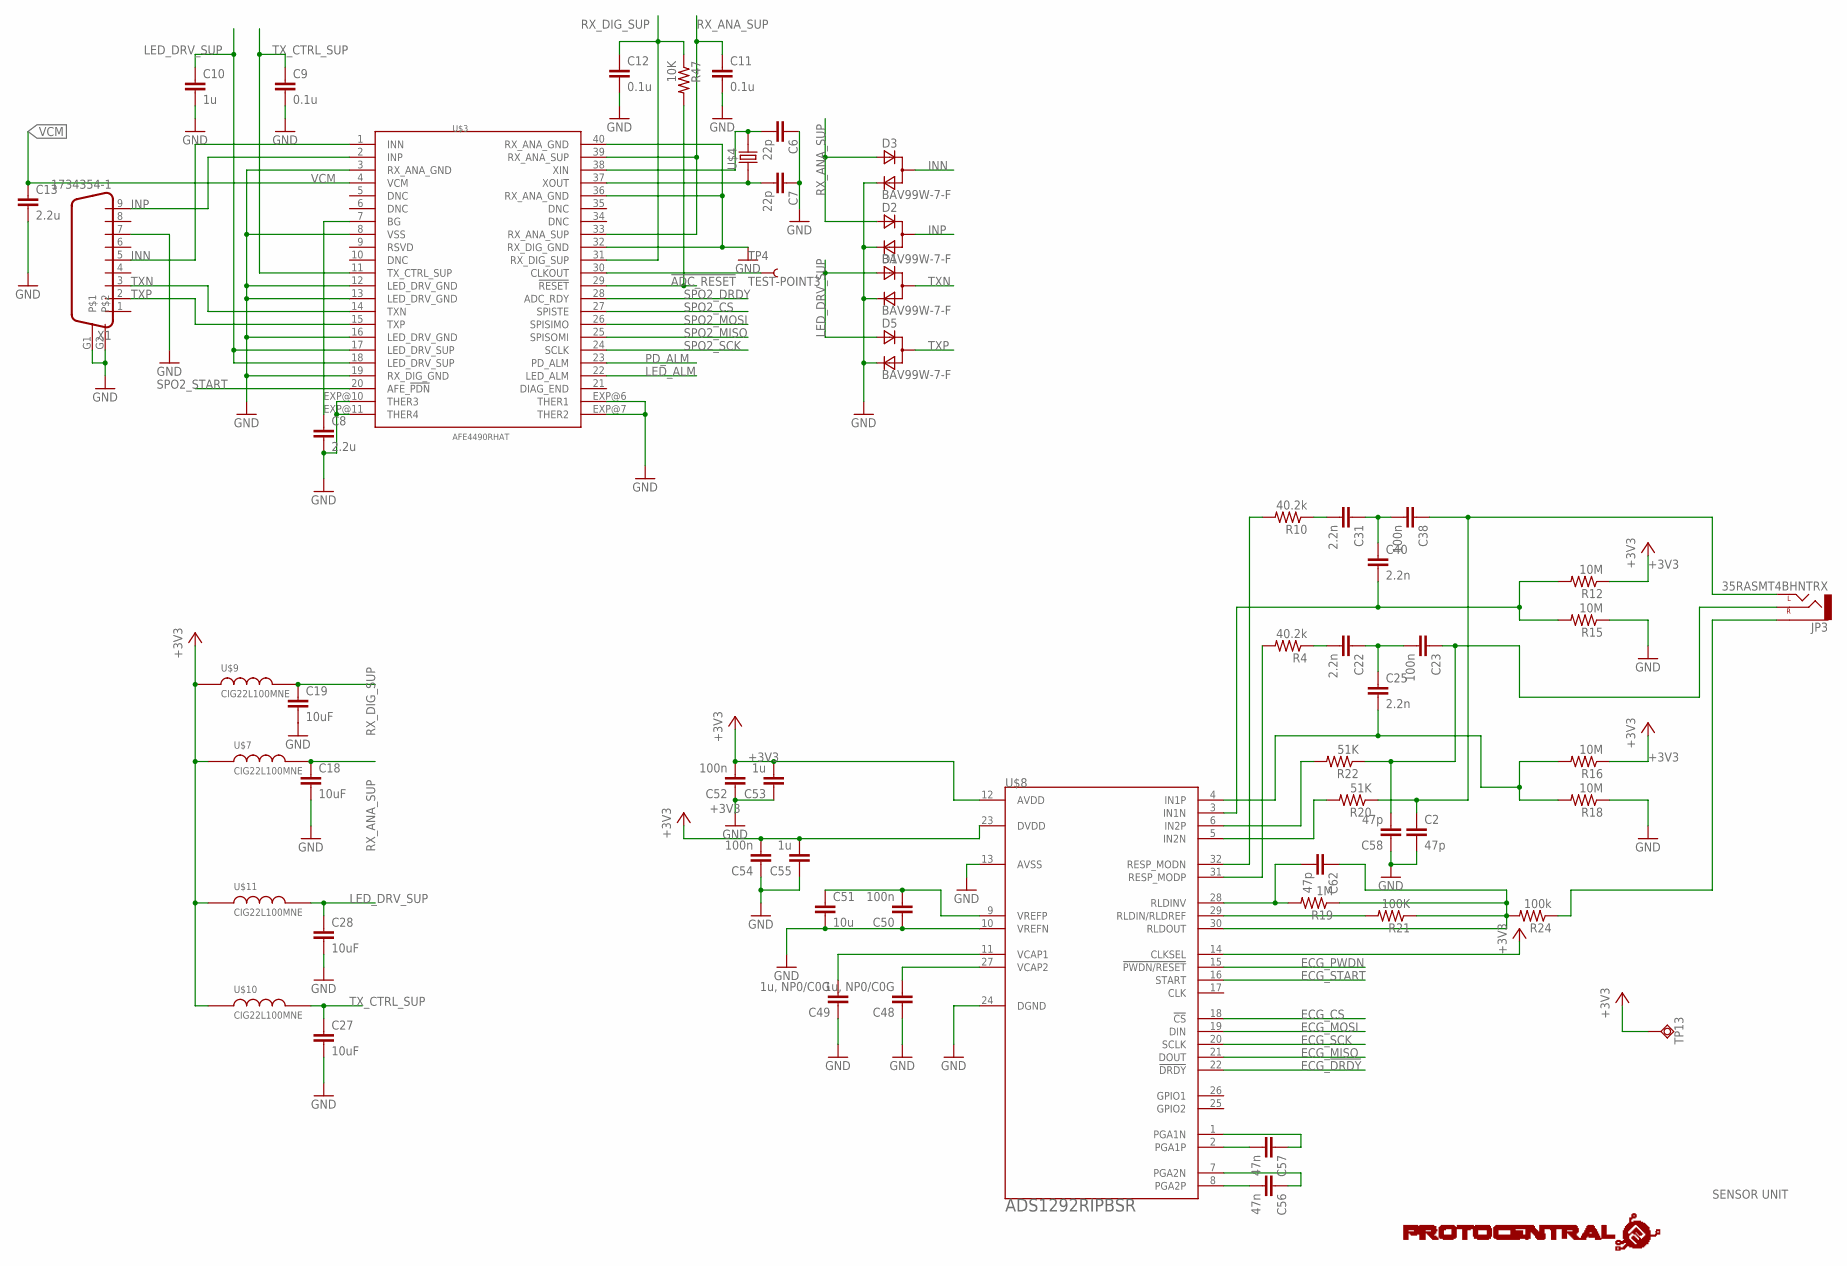
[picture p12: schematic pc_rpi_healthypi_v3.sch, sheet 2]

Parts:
C2, C58, C62: 47p; C0402
C6, C7: 22p; C0402
C8, C13: 2.2u; C0402
C9, C11, C12: 0.1u; C0402
C10: 1u; C0805
C18, C19, C27, C28: 10uF; C0805
C22, C25, C31, C40: 2.2n; C0402
C23, C38, C50, C52, C54: 100n; C0402
C48, C49: 1u, NP0/C0G; C0402
C51: 10u; C0603
C53, C55: 1u; C0402
C56, C57: 47n; C0402
D1, D2, D3, D5: BAV99W-7-F; SOT323
JP3: 35RASMT4BHNTRX; AUDIO-JACK-3.5MM-SMD
R4, R10: 40.2k; R0402
R12, R15, R16, R18: 10M; R0402
R19: 1M; R0402
R20, R22: 51K; R0402
R21: 100K; R0402
R24: 100k; R0402
R47: 10K; R0402
TP4: TEST-POINT3; PAD.03X.03
TP13: TPSQB1,27; B1,27
U$2: PROTY_LOGO_WITH_TEXT; PROTY_WITH_TEXT
U$3: AFE4490RHAT; QFN-40
U$4: ABM3
U$7, U$9, U$10, U$11: CIG22L100MNE; LPS
U$8: ADS1292RIPBSR; SQFP-S-5X5-32
X1: 1734354-1; DB9-STRIGHT

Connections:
!ADC_RESET: R47.2, U$3.29 (!RESET)
+3V3: C52.2, C53.2, C54.2, C55.2, R12.1, R16.1, TP13.TP, U$7.1, U$8.12 (AVDD), U$8.14 (CLKSEL), U$8.23 (DVDD), U$9.1, U$10.1, U$11.1; also elsewhere on the board
ECG_!DRDY: U$8.22 (!DRDY); also elsewhere on the board
ECG_CS: U$8.18 (!CS); also elsewhere on the board
ECG_MISO: U$8.21 (DOUT); also elsewhere on the board
ECG_MOSI: U$8.19 (DIN); also elsewhere on the board
ECG_PWDN: U$8.15 (!PWDN/RESET); also elsewhere on the board
ECG_SCK: U$8.20 (SCLK); also elsewhere on the board
ECG_START: U$8.16 (START); also elsewhere on the board
GND: C2.2, C6.1, C7.1, C8.2, C9.2, C10.2, C11.2, C12.2, C13.2, C18.2, C19.2, C27.2, C28.2, C48.1, C49.1, C50.1, C51.2, C52.1, C53.1, C54.1, C55.1, C58.1, D1.2 (C), D2.2 (C), D3.2 (C), D5.2 (C), R15.1, R18.1, U$3.3 (RX_ANA_GND), U$3.8 (VSS), U$3.12 (LED_DRV_GND), U$3.13 (LED_DRV_GND), U$3.16 (LED_DRV_GND), U$3.19 (RX_DIG_GND), U$3.32 (RX_DIG_GND), U$3.36 (RX_ANA_GND), U$3.40 (RX_ANA_GND), U$3.EXP@6 (THER1), U$3.EXP@7 (THER2), U$3.EXP@10 (THER3), U$3.EXP@11 (THER4), U$8.10 (VREFN), U$8.13 (AVSS), U$8.24 (DGND), X1.7, X1.G1, X1.G2; also elsewhere on the board
INN: D3.1 (CA), U$3.1 (INN), X1.5
INP: D2.1 (CA), U$3.2 (INP), X1.9
LED_ALM: U$3.22 (LED_ALM); also elsewhere on the board
LED_DRV_SUP: C10.1, C28.1, D1.3 (A), D5.3 (A), U$3.17 (LED_DRV_SUP), U$3.18 (LED_DRV_SUP), U$11.2
unnamed: R4.2, U$8.31 (RESP_MODP)
unnamed: C6.2, U$3.38 (XIN), U$4.2
unnamed: C22.2, R4.1
unnamed: C22.1, C23.2, C25.1
unnamed: R22.2, U$8.6 (IN2P)
unnamed: C7.2, U$3.37 (XOUT), U$4.1
unnamed: R20.2, U$8.5 (IN2N)
unnamed: C8.1, U$3.7 (BG)
unnamed: TP4.P$1, U$3.30 (CLKOUT)
unnamed: C48.2, U$8.27 (VCAP2)
unnamed: R10.2, U$8.32 (RESP_MODN)
unnamed: C31.2, R10.1
unnamed: C31.1, C38.2, C40.1
unnamed: C2.1, C38.1, JP3.TIP (LEFT), R20.1
unnamed: C40.2, R12.2, R15.2, U$8.3 (IN1N)
unnamed: C25.2, R16.2, R18.2, U$8.4 (IN1P)
unnamed: R21.2, U$8.29 (RLDIN/RLDREF)
unnamed: C62.2, R19.2, U$8.28 (RLDINV)
unnamed: C49.2, U$8.11 (VCAP1)
unnamed: C56.2, U$8.8 (PGA2P)
unnamed: C56.1, U$8.7 (PGA2N)
unnamed: C50.2, C51.1, U$8.9 (VREFP)
unnamed: C57.2, U$8.2 (PGA1P)
unnamed: C57.1, U$8.1 (PGA1N)
unnamed: C23.1, C58.2, JP3.RING (RIGHT), R22.1
unnamed: C62.1, R19.1, R21.1, R24.2, U$8.30 (RLDOUT)
unnamed: JP3.SLEEVE, R24.1
PD_ALM: U$3.23 (PD_ALM); also elsewhere on the board
RX_ANA_SUP: C11.1, C18.1, D2.3 (A), D3.3 (A), U$3.33 (RX_ANA_SUP), U$3.39 (RX_ANA_SUP), U$7.2
RX_DIG_SUP: C12.1, C19.1, R47.1, U$3.31 (RX_DIG_SUP), U$9.2
SPO2_CS: U$3.27 (SPISTE); also elsewhere on the board
SPO2_DRDY: U$3.28 (ADC_RDY); also elsewhere on the board
SPO2_MISO: U$3.25 (SPISOMI); also elsewhere on the board
SPO2_MOSI: U$3.26 (SPISIMO); also elsewhere on the board
SPO2_SCK: U$3.24 (SCLK); also elsewhere on the board
SPO2_START: U$3.20 (AFE_!PDN); also elsewhere on the board
TXN: D1.1 (CA), U$3.14 (TXN), X1.3
TXP: D5.1 (CA), U$3.15 (TXP), X1.2
TX_CTRL_SUP: C9.1, C27.1, U$3.11 (TX_CTRL_SUP), U$10.2
VCM: C13.1, U$3.4 (VCM)

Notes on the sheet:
SENSOR UNIT

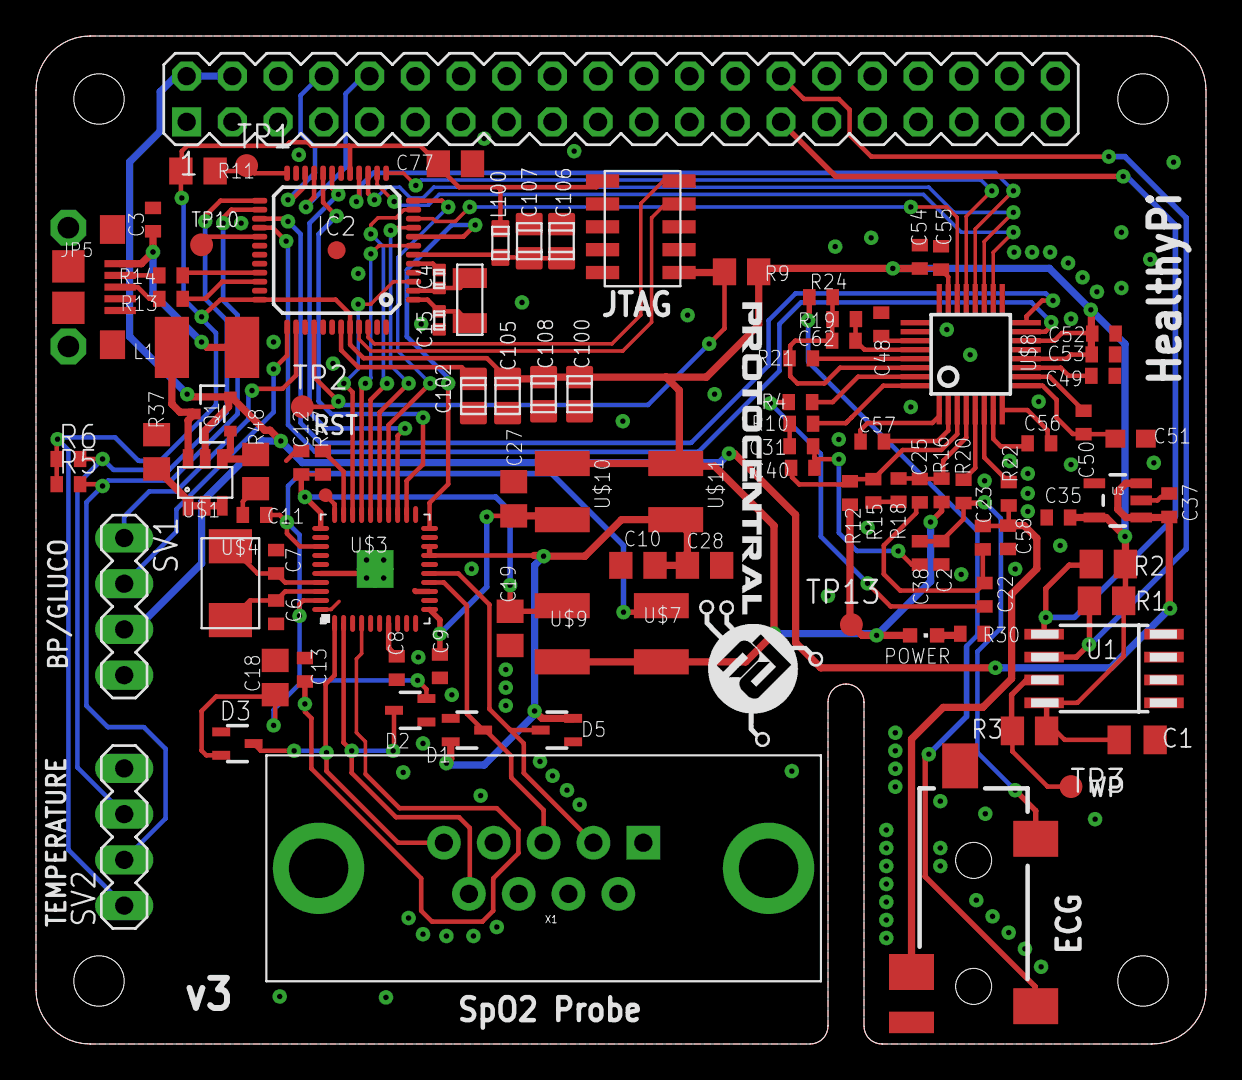
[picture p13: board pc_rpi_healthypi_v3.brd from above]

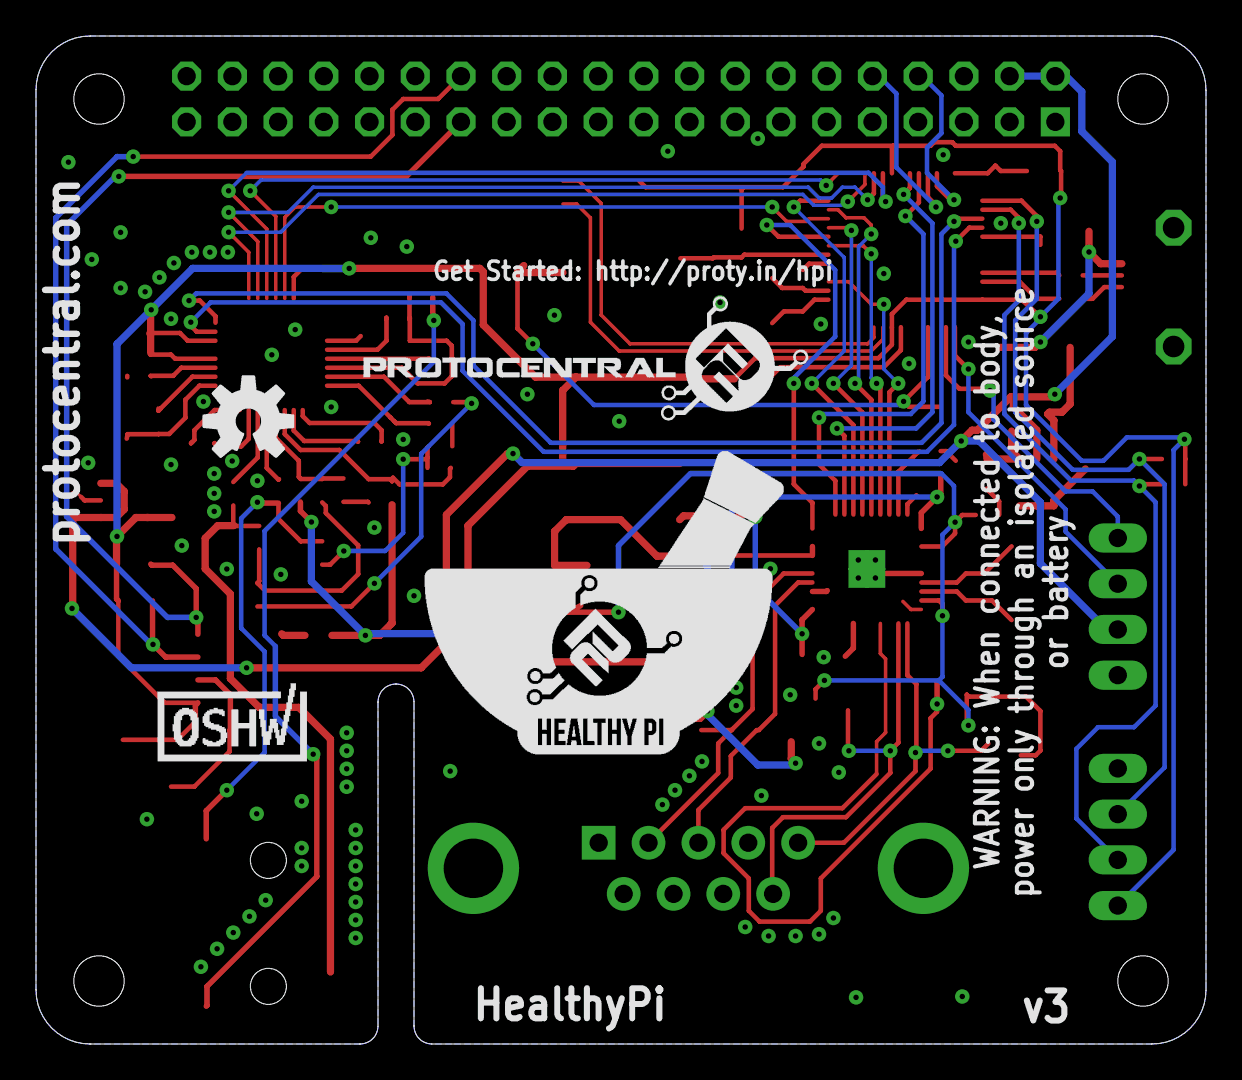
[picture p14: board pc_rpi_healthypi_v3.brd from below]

Board: 4 copper layers, 65.0 x 56.0 mm, 106 parts (4 on the bottom side), 82 nets.

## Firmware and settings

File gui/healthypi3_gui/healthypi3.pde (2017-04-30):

//////////////////////////////////////////////////////////////////////////////////////////
//
//   Desktop GUI for controlling the HealthyPi HAT [ Patient Monitoring System]
//
//   Copyright (c) 2016 ProtoCentral
//   
//   This software is licensed under the MIT License(http://opensource.org/licenses/MIT). 
//   
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
//   Requires g4p_control graphing library for processing.  Built on V4.1
//   Downloaded from Processing IDE Sketch->Import Library->Add Library->G4P Install
//
/////////////////////////////////////////////////////////////////////////////////////////

import g4p_controls.*;                       // Processing GUI Library to create buttons, dropdown,etc.,
import processing.serial.*;                  // Serial Library
import grafica.*;

// Java Swing Package For prompting message
import java.awt.*;
import javax.swing.*;
import static javax.swing.JOptionPane.*;

// File Packages to record the data into a text file
import javax.swing.JFileChooser;
import java.io.FileWriter;
import java.io.BufferedWriter;

// Date Format
import java.util.*;
import java.text.DateFormat;
import java.text.SimpleDateFormat;

// General Java Package
import java.math.*;
import controlP5.*;

ControlP5 cp5;

Textlabel lblHR;
Textlabel lblSPO2;
Textlabel lblRR;
Textlabel lblBP;
Textlabel lblTemp;


/************** Packet Validation  **********************/
private static final int CESState_Init = 0;
private static final int CESState_SOF1_Found = 1;
private static final int CESState_SOF2_Found = 2;
private static final int CESState_PktLen_Found = 3;

/*CES CMD IF Packet Format*/
private static final int CES_CMDIF_PKT_START_1 = 0x0A;
private static final int CES_CMDIF_PKT_START_2 = 0xFA;
private static final int CES_CMDIF_PKT_STOP = 0x0B;

/*CES CMD IF Packet Indices*/
private static final int CES_CMDIF_IND_LEN = 2;
private static final int CES_CMDIF_IND_LEN_MSB = 3;
private static final int CES_CMDIF_IND_PKTTYPE = 4;
private static int CES_CMDIF_PKT_OVERHEAD = 5;

/************** Packet Related Variables **********************/

int ecs_rx_state = 0;                                        // To check the state of the packet
int CES_Pkt_Len;                                             // To store the Packet Length Deatils
int CES_Pkt_Pos_Counter, CES_Data_Counter;                   // Packet and data counter
int CES_Pkt_PktType;                                         // To store the Packet Type
char CES_Pkt_Data_Counter[] = new char[1000];                // Buffer to store the data from the packet
char CES_Pkt_ECG_Counter[] = new char[4];                    // Buffer to hold ECG data
char CES_Pkt_Resp_Counter[] = new char[4];                   // Respiration Buffer
char CES_Pkt_SpO2_Counter_RED[] = new char[4];               // Buffer for SpO2 RED
char CES_Pkt_SpO2_Counter_IR[] = new char[4];                // Buffer for SpO2 IR
int pSize = 500;                                            // Total Size of the buffer
int arrayIndex = 0;                                          // Increment Variable for the buffer
float time = 0;                                              // X axis increment variable

// Buffer for ecg,spo2,respiration,and average of thos values
float[] xdata = new float[pSize];
float[] ecgdata = new float[pSize];
float[] respdata = new float[pSize];
float[] bpmArray = new float[pSize];
float[] ecg_avg = new float[pSize];                          
float[] resp_avg = new float[pSize];
float[] spo2data = new float[pSize];
float[] spo2Array_IR = new float[pSize];
float[] spo2Array_RED = new float[pSize];
float[] rpmArray = new float[pSize];
float[] ppgArray = new float[pSize];

/************** User Defined Class Objects **********************/

BPM hr;
RPM rpm1;
SPO2_cal s;

/************** Graph Related Variables **********************/

double maxe, mine, maxr, minr, maxs, mins;             // To Calculate the Minimum and Maximum of the Buffer
double ecg, resp, spo2_ir, spo2_red, spo2, redAvg, irAvg, ecgAvg, resAvg;  // To store the current ecg value
double respirationVoltage=20;                          // To store the current respiration value
boolean startPlot = false;                             // Conditional Variable to start and stop the plot

GPlot plotPPG;
GPlot plotECG;
GPlot plotResp;

int step = 0;
int stepsPerCycle = 100;
int lastStepTime = 0;
boolean clockwise = true;
float scale = 5;

/************** File Related Variables **********************/

boolean logging = false;                                // Variable to check whether to record the data or not
FileWriter output;                                      // In-built writer class object to write the data to file
JFileChooser jFileChooser;                              // Helps to choose particular folder to save the file
Date date;                                              // Variables to record the date related values                              
BufferedWriter bufferedWriter;
DateFormat dateFormat;

/************** Port Related Variables **********************/

Serial port = null;                                     // Oject for communicating via serial port
String[] comList;                                       // Buffer that holds the serial ports that are paired to the laptop
char inString = '\0';                                   // To receive the bytes from the packet
String selectedPort;                                    // Holds the selected port number

/************** Logo Related Variables **********************/

PImage logo;
boolean gStatus;                                        // Boolean variable to save the grid visibility status

int nPoints1 = pSize;
int totalPlotsHeight=0;
int totalPlotsWidth=0;
int heightHeader=50;

boolean is_raspberrypi=true;
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

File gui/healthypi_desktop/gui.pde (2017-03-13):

/* =========================================================
 * ====                   WARNING                        ===
 * =========================================================
 * The code in this tab has been generated from the GUI form
 * designer and care should be taken when editing this file.
 * Only add/edit code inside the event handlers i.e. only
 * use lines between the matching comment tags. e.g.

 void myBtnEvents(GButton button) { //_CODE_:button1:12356:
     // It is safe to enter your event code here  
 } //_CODE_:button1:12356:
 
 * Do not rename this tab!
 * =========================================================
 */

public void portList_click(GDropList source, GEvent event) { //_CODE_:portList:640344:
  //println("portList - GDropList >> GEvent." + event + " @ " + millis());
  selectedPort = portList.getSelectedText();
  startSerial();
} //_CODE_:portList:640344:

public void record_click(GButton source, GEvent event) { //_CODE_:record:731936:
  //println("record - GButton >> GEvent." + event + " @ " + millis());
  ////////////////////////////////////////////////////////////////////////////////
  //
  //    Enable the buttons and calls the serial port function
  //    Comselect is made true to call the serial function
  //  
  ///////////////////////////////////////////////////////////////////////////////
  try
  {
    jFileChooser = new JFileChooser();
    jFileChooser.setSelectedFile(new File("log.csv"));
    jFileChooser.showSaveDialog(null);
    String filePath = jFileChooser.getSelectedFile()+"";

    if ((filePath.equals("log.txt"))||(filePath.equals("null")))
    {
    } else
    {    
      done.setVisible(true);
      record.setVisible(false);
      close.setEnabled(false);
      close.setLocalColorScheme(GCScheme.CYAN_SCHEME);
      logging = true;
      date = new Date();
      output = new FileWriter(jFileChooser.getSelectedFile(), true);
      bufferedWriter = new BufferedWriter(output);
      bufferedWriter.write(date.toString()+"");
      bufferedWriter.newLine();
      bufferedWriter.write("TimeStramp,ECG,SpO2,Respiration");
      bufferedWriter.newLine();
    }
  }
  catch(Exception e)
  {
    println("File Not Found");
  }
} //_CODE_:record:731936:

public void done_click(GButton source, GEvent event) { //_CODE_:done:614170:
  //println("done - GButton >> GEvent." + event + " @ " + millis());
  ////////////////////////////////////////////////////////////////////////////////
  //
  //    Save the file and displays a success message
  //  
  ///////////////////////////////////////////////////////////////////////////////
  if (logging == true)
  {
    showMessageDialog(null, "Log File Saved successfully");

    record.setVisible(true);
    done.setVisible(false);

    close.setEnabled(true);
    close.setLocalColorScheme(GCScheme.GREEN_SCHEME);
    record.setEnabled(true);
    record.setLocalColorScheme(GCScheme.GREEN_SCHEME);
    done.setEnabled(true);
    done.setLocalColorScheme(GCScheme.GREEN_SCHEME);
    logging = false;
    try
    {
      bufferedWriter.flush();
      bufferedWriter.close();
    }
    catch(Exception e)
    {
      println(e);
    }
  }
} //_CODE_:done:614170:

public void close_click(GButton source, GEvent event) { //_CODE_:close:222350:
  //println("close - GButton >> GEvent." + event + " @ " + millis());
  int dialogResult = JOptionPane.showConfirmDialog (null, "Would You Like to Close The Application?");
  if (dialogResult == JOptionPane.YES_OPTION) {
    try
    {
      Runtime runtime = Runtime.getRuntime();
      Process proc = runtime.exec("sudo shutdown -h now");
      System.exit(0);
    }
    catch(Exception e)
    {
      exit();
    }
  } else
  {
  }
} //_CODE_:close:222350:

public void imgButton1_click1(GImageButton source, GEvent event) { //_CODE_:imgButton1:665258:
  println("imgButton1 - GImageButton >> GEvent." + event + " @ " + millis());
} //_CODE_:imgButton1:665258:

public void grid_size_click(GButton source, GEvent event) { //_CODE_:grid_size:708711:
  println("grid_size - GButton >> GEvent." + event + " @ " + millis());
} //_CODE_:grid_size:708711:

public void gridStatus_click(GButton source, GEvent event) { //_CODE_:gridStatus:949626:
  //println("gridStatus - GButton >> GEvent." + event + " @ " + millis());
  if (gStatus)
  {
    gStatus = false;
    la.setText("Grid :OFF");
  } else
  {
    gStatus = true;    
    la.setText("Grid :   ON");
  }
  la.setTextBold();
} //_CODE_:gridStatus:949626:
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

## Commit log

2016-09-30 Raspberry Pi Configured Code
    [read.csv]
2016-09-30 Raspberry Pi Output
2017-01-20 Updated HealthyPi v2 schematics
    [pc_healthypi_v1.brd, pc_healthypi_v1.sch, pc_rpi_healthypi.brd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]
2017-02-16 Added HealthyPi Arduino Support
2017-02-24 Removed drivers from source
2017-04-30 Added HealthyPi v3 Schematics
    [pc_rpi_healthypi_v3.brd, pc_rpi_healthypi_v3.sch]

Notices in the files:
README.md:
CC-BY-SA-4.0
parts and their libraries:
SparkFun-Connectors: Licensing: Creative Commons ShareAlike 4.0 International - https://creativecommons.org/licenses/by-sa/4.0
